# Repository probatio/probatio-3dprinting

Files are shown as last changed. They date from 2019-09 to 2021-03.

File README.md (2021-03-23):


# probatio-3dprinting
Probatio's models for 3D printing

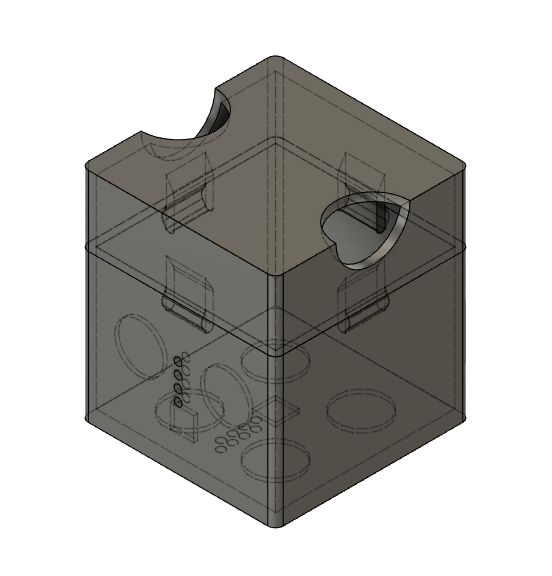
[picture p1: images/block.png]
probatio-block-3dp


[Model in Fusion 360](https://a360.co/2OMQyPX)

## Lateral support (2 parts)

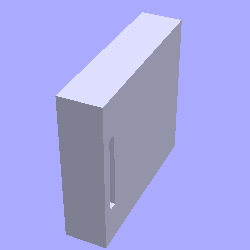
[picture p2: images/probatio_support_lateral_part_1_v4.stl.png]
probatio_support_lateral_part_1_v4


[probatio_support_lateral_part_1_v4](https://github.com/probatio/probatio-3dprinting/blob/master/stls/probatio_support_lateral_part_1_v4.stl)

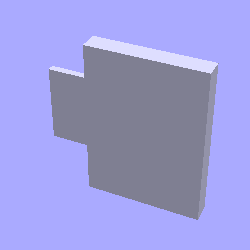
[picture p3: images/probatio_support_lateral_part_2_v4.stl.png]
probatio_support_lateral_part_2_v4


[probatio_support_lateral_part_2_v4](https://github.com/probatio/probatio-3dprinting/blob/master/stls/probatio_support_lateral_part_2_v4.stl)

## Lateral support (single part)

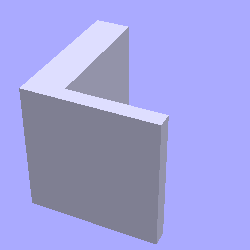
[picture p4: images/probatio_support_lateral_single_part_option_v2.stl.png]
probatio_support_lateral_single_part_option_v2


[probatio_support_lateral_single_part_option_v2](https://github.com/probatio/probatio-3dprinting/blob/master/stls/probatio_support_lateral_single_part_option_v2.stl)

## Neck support for Base 1x3

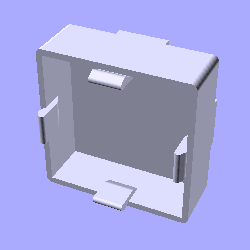
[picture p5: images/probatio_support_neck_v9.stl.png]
probatio_support_neck_v9


[probatio_support_neck_v9](https://github.com/probatio/probatio-3dprinting/blob/master/stls/probatio_support_neck_v9.stl)

## Hub Case (for M5StickC)

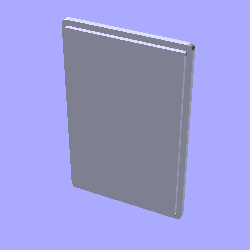
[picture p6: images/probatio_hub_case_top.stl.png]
probatio_hub_case_top


[probatio_hub_case_top](https://github.com/probatio/probatio-3dprinting/blob/master/stls/probatio_hub_case_top.stl)

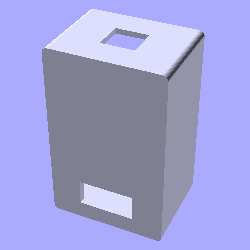
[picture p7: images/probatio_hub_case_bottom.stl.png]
probatio_hub_case_bottom


[probatio_hub_case_bottom](https://github.com/probatio/probatio-3dprinting/blob/master/stls/probatio_hub_case_bottom.stl)

## Block Tops

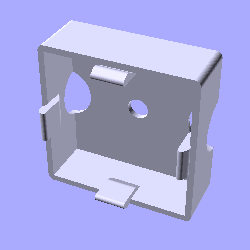
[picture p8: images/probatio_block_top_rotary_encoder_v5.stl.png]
probatio_block_top_rotary_encoder_v5


[probatio_block_top_rotary_encoder_v5](https://github.com/probatio/probatio-3dprinting/blob/master/stls/probatio_block_top_rotary_encoder_v5.stl)

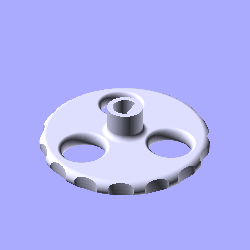
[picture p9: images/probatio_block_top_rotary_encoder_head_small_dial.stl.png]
probatio_block_top_rotary_encoder_head_small_dial


[probatio_block_top_rotary_encoder_head_small_dial](https://github.com/probatio/probatio-3dprinting/blob/master/stls/probatio_block_top_rotary_encoder_head_small_dial.stl)

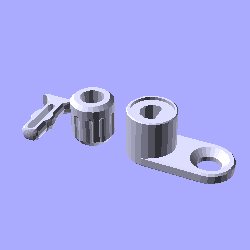
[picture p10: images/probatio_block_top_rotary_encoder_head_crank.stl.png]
probatio_block_top_rotary_encoder_head_crank


[probatio_block_top_rotary_encoder_head_crank](https://github.com/probatio/probatio-3dprinting/blob/master/stls/probatio_block_top_rotary_encoder_head_crank.stl)

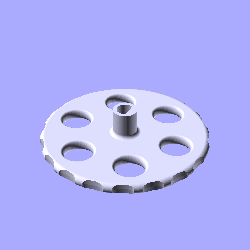
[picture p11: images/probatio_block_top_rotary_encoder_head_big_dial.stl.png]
probatio_block_top_rotary_encoder_head_big_dial


[probatio_block_top_rotary_encoder_head_big_dial](https://github.com/probatio/probatio-3dprinting/blob/master/stls/probatio_block_top_rotary_encoder_head_big_dial.stl)

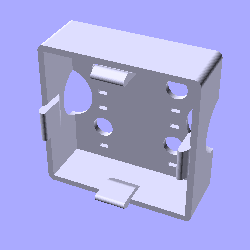
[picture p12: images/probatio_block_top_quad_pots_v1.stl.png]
probatio_block_top_quad_pots_v1


[probatio_block_top_quad_pots_v1](https://github.com/probatio/probatio-3dprinting/blob/master/stls/probatio_block_top_quad_pots_v1.stl)

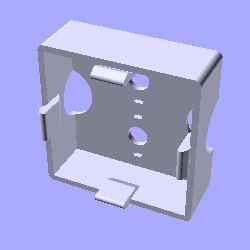
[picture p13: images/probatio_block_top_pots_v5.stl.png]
probatio_block_top_pots_v5


[probatio_block_top_pots_v5](https://github.com/probatio/probatio-3dprinting/blob/master/stls/probatio_block_top_pots_v5.stl)

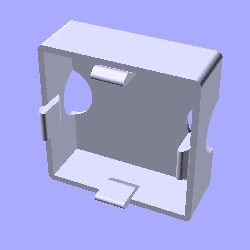
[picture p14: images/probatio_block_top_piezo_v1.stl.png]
probatio_block_top_piezo_v1


[probatio_block_top_piezo_v1](https://github.com/probatio/probatio-3dprinting/blob/master/stls/probatio_block_top_piezo_v1.stl)

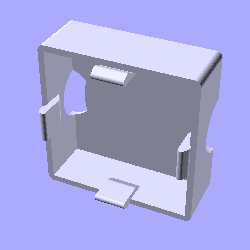
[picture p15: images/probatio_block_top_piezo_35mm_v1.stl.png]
probatio_block_top_piezo_35mm_v1


[probatio_block_top_piezo_35mm_v1](https://github.com/probatio/probatio-3dprinting/blob/master/stls/probatio_block_top_piezo_35mm_v1.stl)

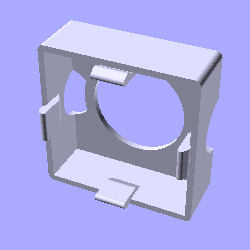
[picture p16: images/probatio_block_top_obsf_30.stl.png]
probatio_block_top_obsf_30


[probatio_block_top_obsf_30](https://github.com/probatio/probatio-3dprinting/blob/master/stls/probatio_block_top_obsf_30.stl)

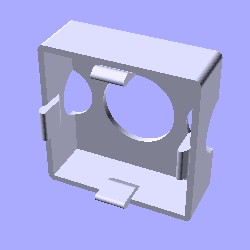
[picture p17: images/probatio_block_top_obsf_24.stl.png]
probatio_block_top_obsf_24


[probatio_block_top_obsf_24](https://github.com/probatio/probatio-3dprinting/blob/master/stls/probatio_block_top_obsf_24.stl)

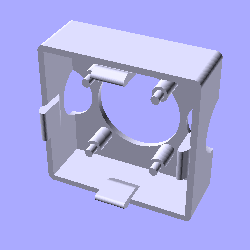
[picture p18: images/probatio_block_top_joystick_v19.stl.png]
probatio_block_top_joystick_v19


[probatio_block_top_joystick_v19](https://github.com/probatio/probatio-3dprinting/blob/master/stls/probatio_block_top_joystick_v19.stl)

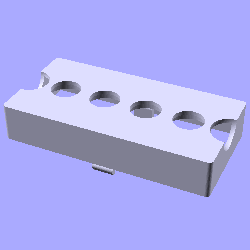
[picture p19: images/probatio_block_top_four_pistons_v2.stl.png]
probatio_block_top_four_pistons_v2


[probatio_block_top_four_pistons_v2](https://github.com/probatio/probatio-3dprinting/blob/master/stls/probatio_block_top_four_pistons_v2.stl)

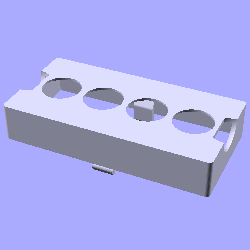
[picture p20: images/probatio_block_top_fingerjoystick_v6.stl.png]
probatio_block_top_fingerjoystick_v6


[probatio_block_top_fingerjoystick_v6](https://github.com/probatio/probatio-3dprinting/blob/master/stls/probatio_block_top_fingerjoystick_v6.stl)

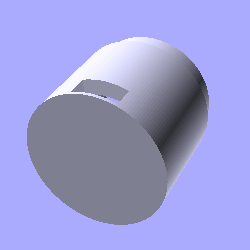
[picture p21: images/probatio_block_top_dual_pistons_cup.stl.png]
probatio_block_top_dual_pistons_cup


[probatio_block_top_dual_pistons_cup](https://github.com/probatio/probatio-3dprinting/blob/master/stls/probatio_block_top_dual_pistons_cup.stl)

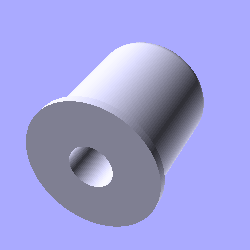
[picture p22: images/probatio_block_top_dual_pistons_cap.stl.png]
probatio_block_top_dual_pistons_cap


[probatio_block_top_dual_pistons_cap](https://github.com/probatio/probatio-3dprinting/blob/master/stls/probatio_block_top_dual_pistons_cap.stl)

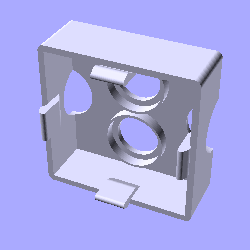
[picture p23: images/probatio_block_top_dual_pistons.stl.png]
probatio_block_top_dual_pistons


[probatio_block_top_dual_pistons](https://github.com/probatio/probatio-3dprinting/blob/master/stls/probatio_block_top_dual_pistons.stl)

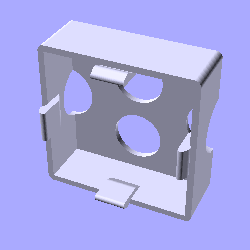
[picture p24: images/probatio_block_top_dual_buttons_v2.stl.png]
probatio_block_top_dual_buttons_v2


[probatio_block_top_dual_buttons_v2](https://github.com/probatio/probatio-3dprinting/blob/master/stls/probatio_block_top_dual_buttons_v2.stl)

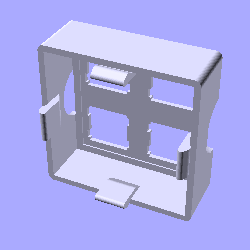
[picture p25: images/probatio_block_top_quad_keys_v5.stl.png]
probatio_block_top_quad_keys_v5


[probatio_block_top_quad_keys_v5](https://github.com/probatio/probatio-3dprinting/blob/master/stls/probatio_block_top_quad_keys_v5.stl)

probatio_block_top_breath_v1

[probatio_block_top_breath_v1](https://github.com/probatio/probatio-3dprinting/blob/master/stls/probatio_block_top_breath_v1.stl)

## Block Bottom 1x1

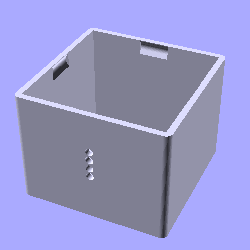
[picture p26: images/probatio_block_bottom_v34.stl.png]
probatio_block_bottom_v34


[probatio_block_bottom_v34](https://github.com/probatio/probatio-3dprinting/blob/master/stls/probatio_block_bottom_v34.stl)

## Block Joystick 4-DOFs 3x3

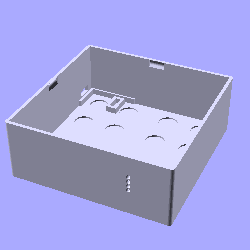
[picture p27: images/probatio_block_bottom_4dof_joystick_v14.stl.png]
probatio_block_bottom_4dof_joystick_v14


[probatio_block_bottom_4dof_joystick_v14](https://github.com/probatio/probatio-3dprinting/blob/master/stls/probatio_block_bottom_4dof_joystick_v14.stl)

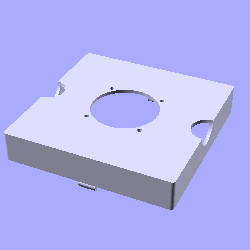
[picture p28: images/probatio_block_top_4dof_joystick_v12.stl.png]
probatio_block_top_4dof_joystick_v12


[probatio_block_top_4dof_joystick_v12](https://github.com/probatio/probatio-3dprinting/blob/master/stls/probatio_block_top_4dof_joystick_v12.stl)

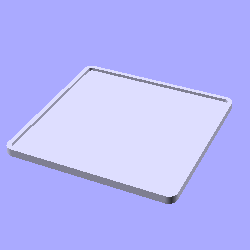
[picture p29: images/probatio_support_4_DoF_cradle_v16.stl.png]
probatio_support_4_DoF_cradle_v16


[probatio_support_4_DoF_cradle_v16](https://github.com/probatio/probatio-3dprinting/blob/master/stls/probatio_support_4_DoF_cradle_v16.stl)

## Bases

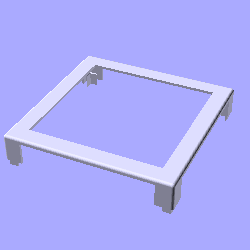
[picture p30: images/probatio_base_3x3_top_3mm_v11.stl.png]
probatio_base_3x3_top_3mm_v11


[probatio_base_3x3_top_3mm_v11](https://github.com/probatio/probatio-3dprinting/blob/master/stls/probatio_base_3x3_top_3mm_v11.stl)

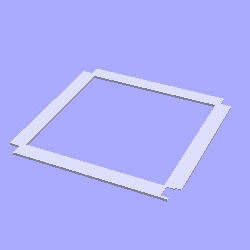
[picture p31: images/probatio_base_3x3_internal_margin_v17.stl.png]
probatio_base_3x3_internal_margin_v17


[probatio_base_3x3_internal_margin_v17](https://github.com/probatio/probatio-3dprinting/blob/master/stls/probatio_base_3x3_internal_margin_v17.stl)

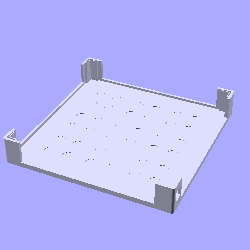
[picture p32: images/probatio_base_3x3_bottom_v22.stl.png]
probatio_base_3x3_bottom_v22


[probatio_base_3x3_bottom_v22](https://github.com/probatio/probatio-3dprinting/blob/master/stls/probatio_base_3x3_bottom_v22.stl)

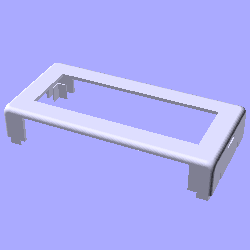
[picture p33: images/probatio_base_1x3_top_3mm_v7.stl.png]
probatio_base_1x3_top_3mm_v7


[probatio_base_1x3_top_3mm_v7](https://github.com/probatio/probatio-3dprinting/blob/master/stls/probatio_base_1x3_top_3mm_v7.stl)

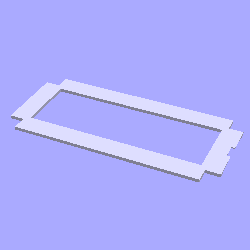
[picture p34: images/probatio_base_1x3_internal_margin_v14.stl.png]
probatio_base_1x3_internal_margin_v14


[probatio_base_1x3_internal_margin_v14](https://github.com/probatio/probatio-3dprinting/blob/master/stls/probatio_base_1x3_internal_margin_v14.stl)

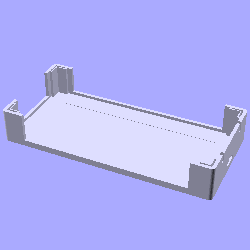
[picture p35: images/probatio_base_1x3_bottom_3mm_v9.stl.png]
probatio_base_1x3_bottom_3mm_v9


[probatio_base_1x3_bottom_3mm_v9](https://github.com/probatio/probatio-3dprinting/blob/master/stls/probatio_base_1x3_bottom_3mm_v9.stl)

## Dummy Blocks (for support)

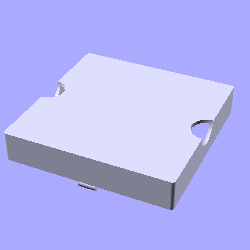
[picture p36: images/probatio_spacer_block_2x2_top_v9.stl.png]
probatio_spacer_block_2x2_top_v9


[probatio_spacer_block_2x2_top_v9](https://github.com/probatio/probatio-3dprinting/blob/master/stls/probatio_spacer_block_2x2_top_v9.stl)

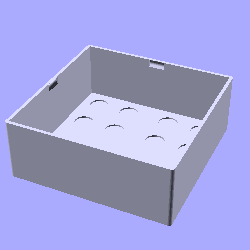
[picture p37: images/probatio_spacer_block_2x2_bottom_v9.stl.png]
probatio_spacer_block_2x2_bottom_v9


[probatio_spacer_block_2x2_bottom_v9](https://github.com/probatio/probatio-3dprinting/blob/master/stls/probatio_spacer_block_2x2_bottom_v9.stl)

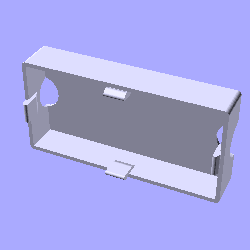
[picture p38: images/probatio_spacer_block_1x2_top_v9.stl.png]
probatio_spacer_block_1x2_top_v9


[probatio_spacer_block_1x2_top_v9](https://github.com/probatio/probatio-3dprinting/blob/master/stls/probatio_spacer_block_1x2_top_v9.stl)

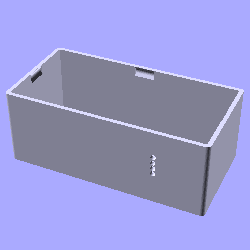
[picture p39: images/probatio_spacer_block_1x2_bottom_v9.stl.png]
probatio_spacer_block_1x2_bottom_v9


[probatio_spacer_block_1x2_bottom_v9](https://github.com/probatio/probatio-3dprinting/blob/master/stls/probatio_spacer_block_1x2_bottom_v9.stl)

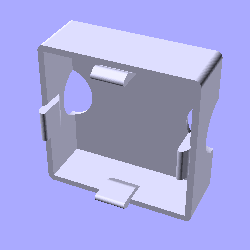
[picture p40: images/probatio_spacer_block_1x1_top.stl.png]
probatio_spacer_block_1x1_top


[probatio_spacer_block_1x1_top](https://github.com/probatio/probatio-3dprinting/blob/master/stls/probatio_spacer_block_1x1_top.stl)

probatio_spacer_block_1x1_bottom

[probatio_spacer_block_1x1_bottom](https://github.com/probatio/probatio-3dprinting/blob/master/stls/probatio_spacer_block_1x1_bottom.stl)

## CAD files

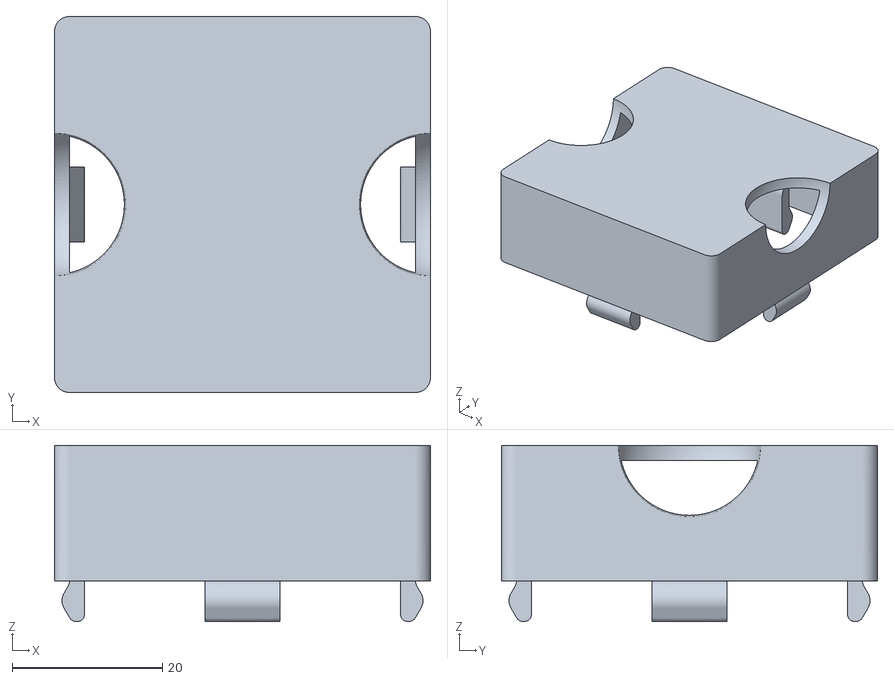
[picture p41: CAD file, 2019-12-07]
probatio-block-3dp-top-side-holes.stl
50.0 x 50.0 x 23.4

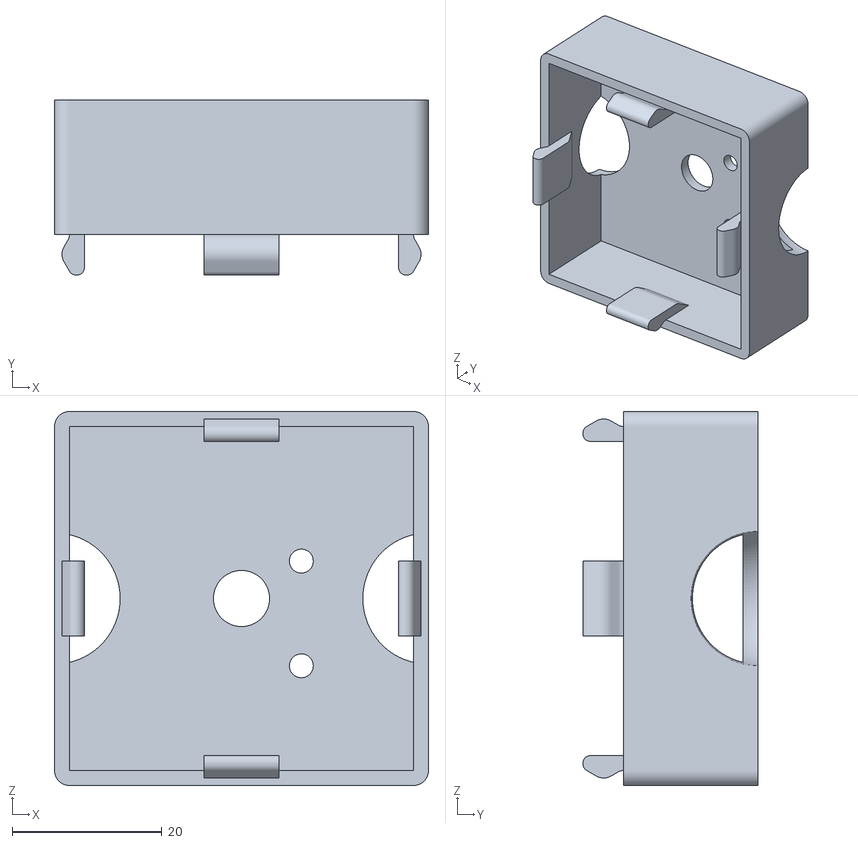
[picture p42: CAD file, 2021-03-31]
stls/probatio_block_top_rotary_encoder_unthreaded_with_breakout_board_v2.stl
50.0 x 23.4 x 50.0

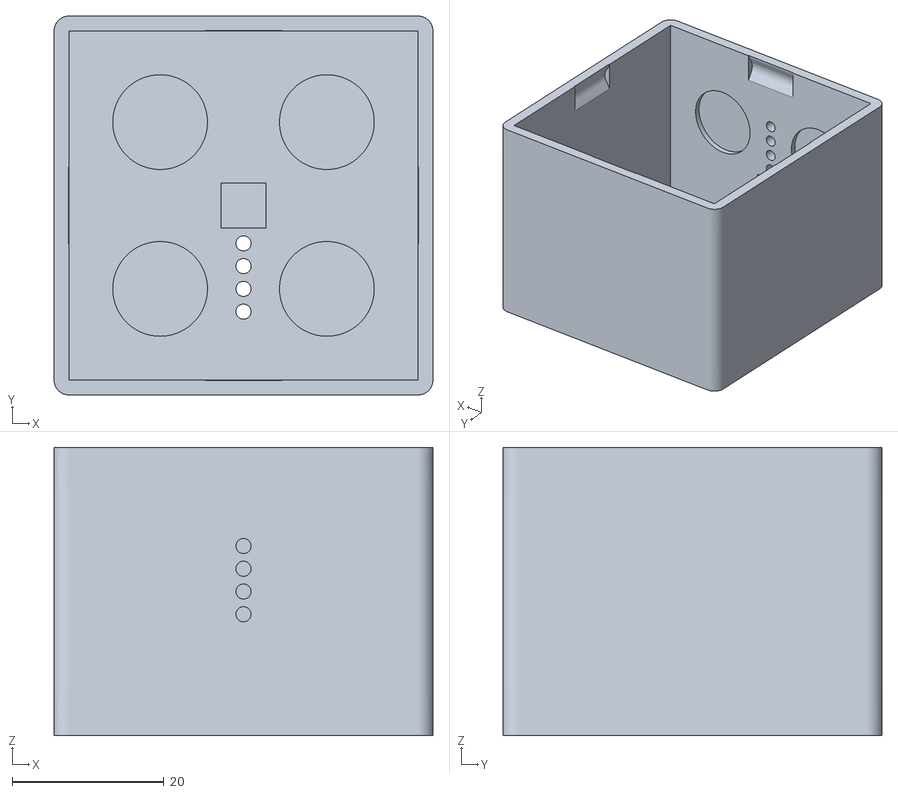
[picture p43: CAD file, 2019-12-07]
probatio-block-3dp-bottom-side-holes.stl
50.0 x 50.0 x 38.0

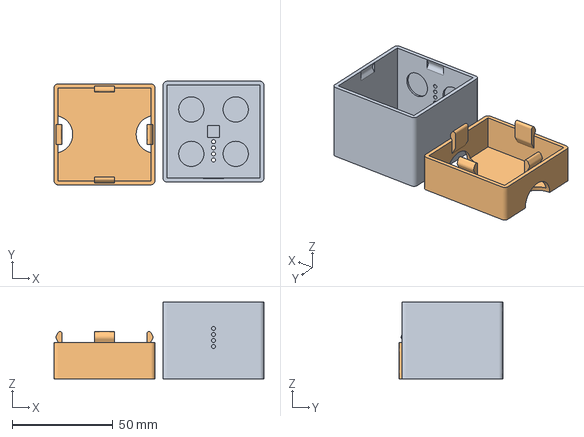
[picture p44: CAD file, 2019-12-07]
CE3_topbottom_probatio-block-3dp-.3mf
104.0 x 51.3 x 38.0 mm

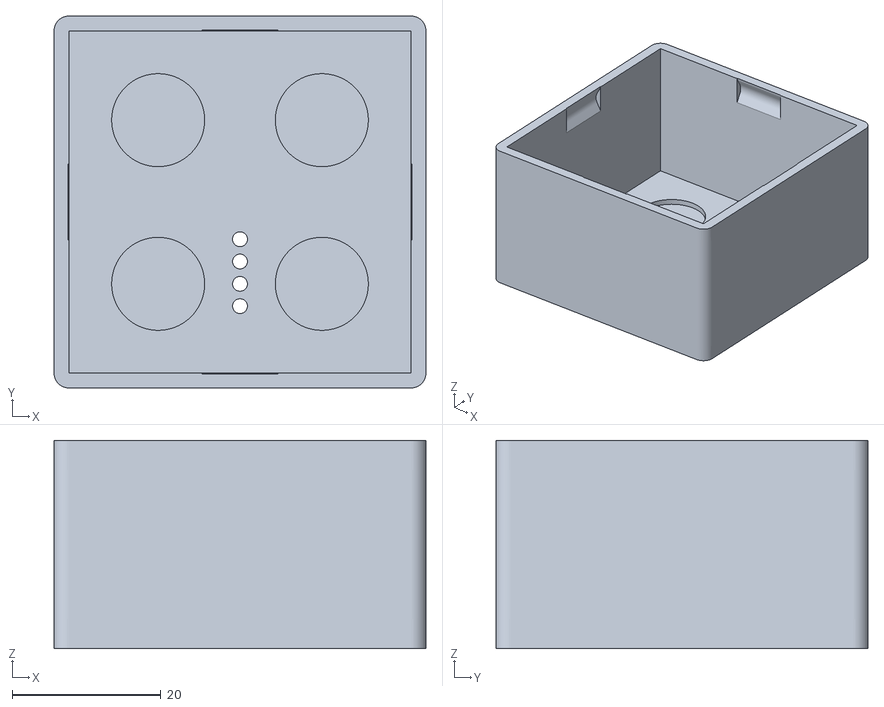
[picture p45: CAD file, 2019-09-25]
probatio-block-3dp-bottom.stl
50.0 x 50.0 x 28.0

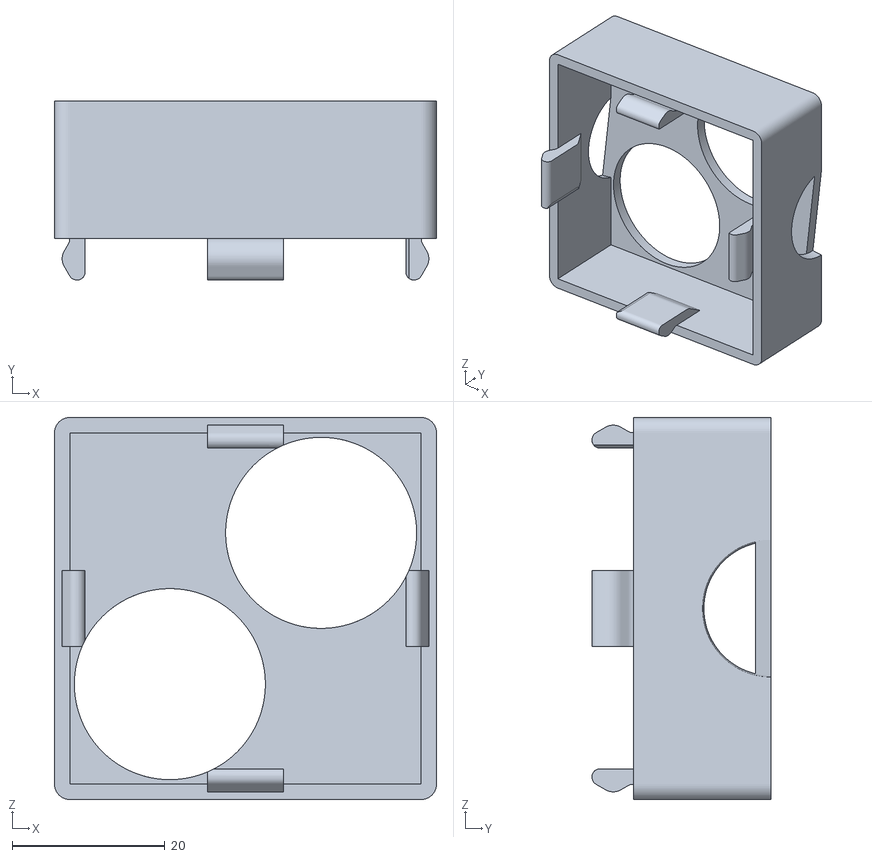
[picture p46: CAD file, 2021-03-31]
stls/probatio_block_top_dual_obsf_v1.stl
50.0 x 23.4 x 50.0

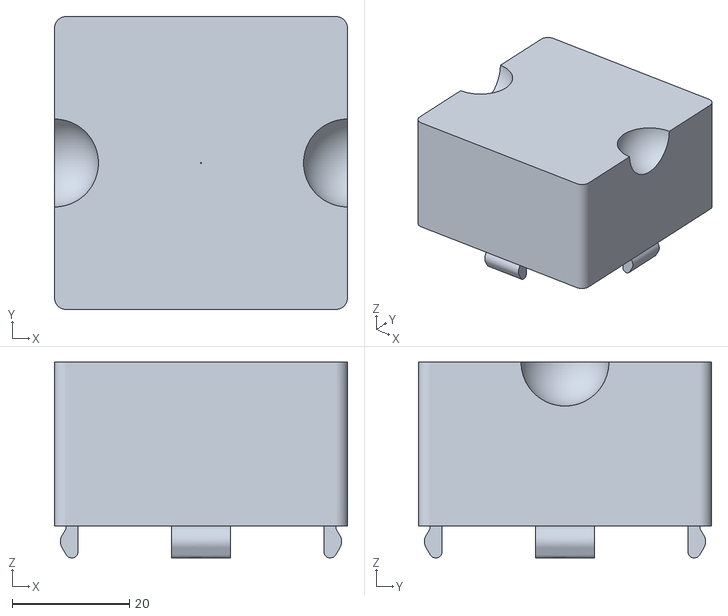
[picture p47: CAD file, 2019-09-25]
probatio-block-3dp-top.stl
50.0 x 50.0 x 33.4

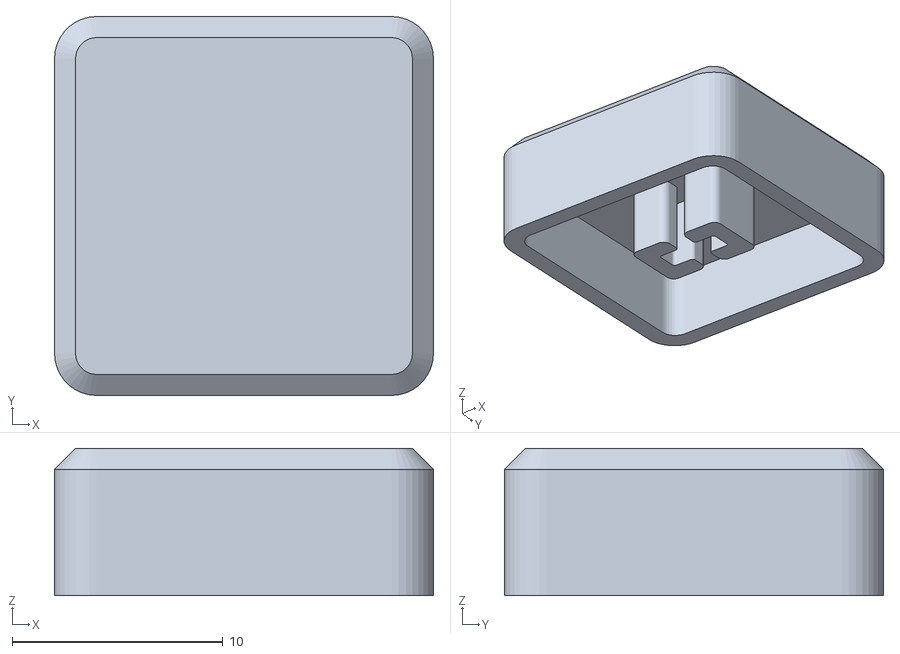
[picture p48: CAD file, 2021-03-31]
stls/probatio_block_top_quad_keys_keycap_v1.stl
18.0 x 18.0 x 7.00

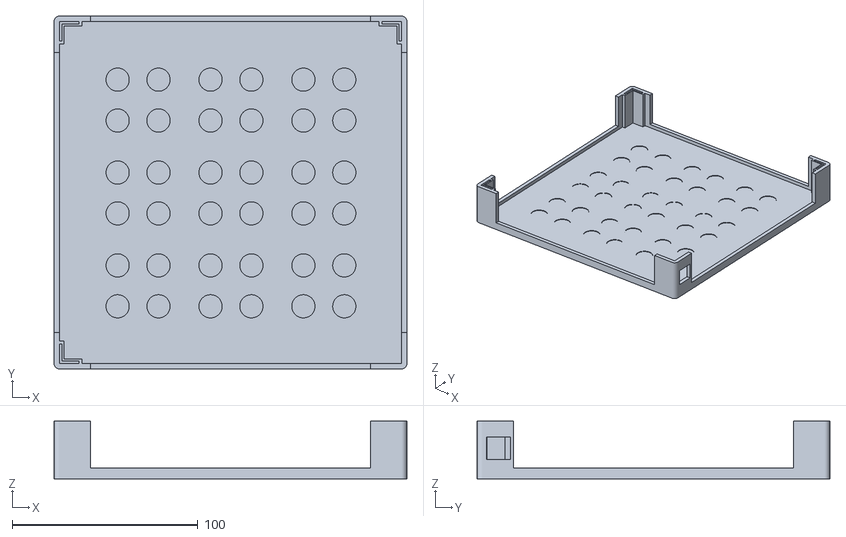
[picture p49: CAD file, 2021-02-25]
stls/probatio_base_3x3_bottom_v22.stl
190.0 x 190.0 x 31.0

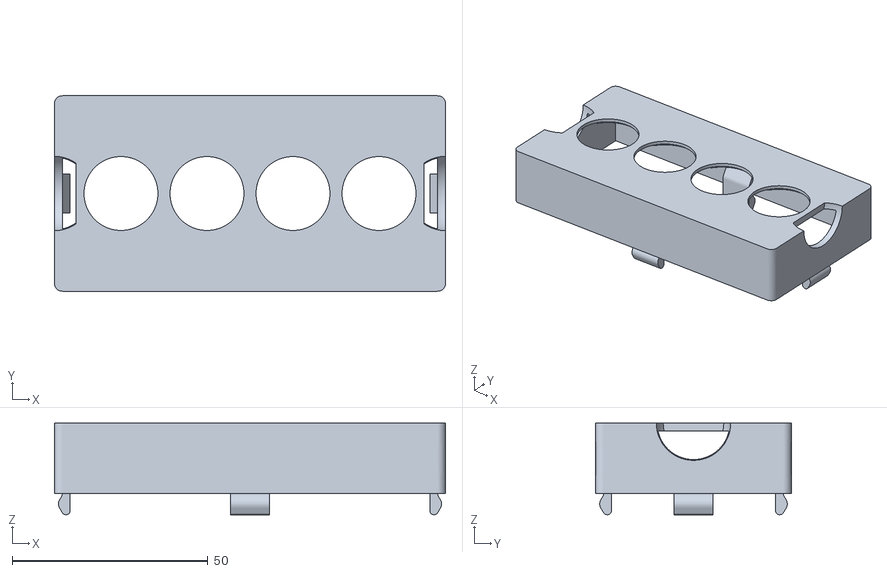
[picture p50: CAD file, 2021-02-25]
stls/probatio_block_top_fingerjoystick_v6.stl
100.0 x 50.0 x 23.4

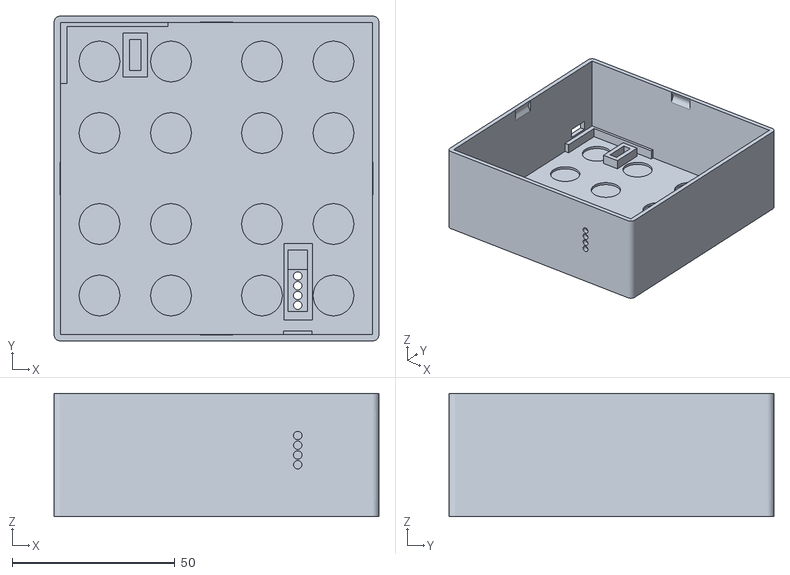
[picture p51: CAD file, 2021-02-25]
stls/probatio_block_bottom_4dof_joystick_v14.stl
100.0 x 100.0 x 38.0

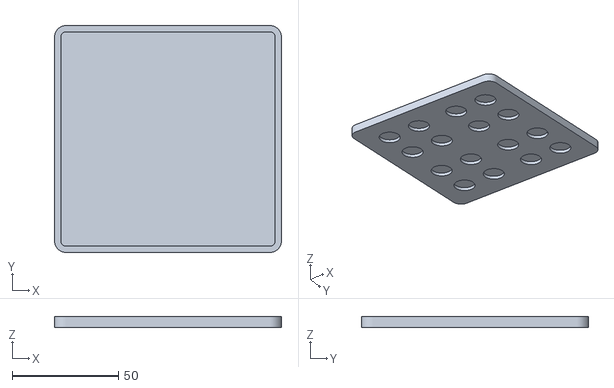
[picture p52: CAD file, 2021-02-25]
stls/probatio_support_4_DoF_cradle_v16.stl
107.0 x 107.0 x 5.00

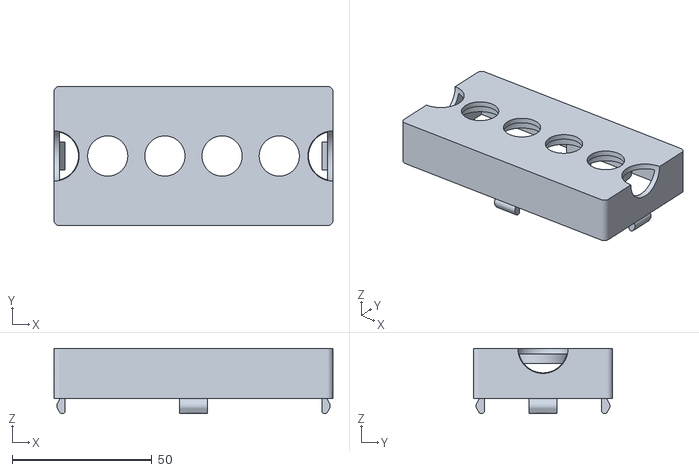
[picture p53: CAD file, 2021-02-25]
stls/probatio_block_top_four_pistons_v2.stl
100.0 x 50.0 x 23.4

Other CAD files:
stls/probatio_block_top_midi_usb_din_v1.stl
stls/probatio_block_top_midi_usb_din_rj12_v1.stl
stls/probatio_block_top_quad_buttons_v1.stl
stls/probatio_block_top_quad_pots_v3.stl
stls/probatio_block_top_obsf_30.stl
fusion360/Class_ Block (parametric generator) v9.f3d
fusion360/Class_ Block Top (generator) v4.f3z
fusion360/Probatio Assembly 1.0 v9.f3z
fusion360/Probatio_Pogo v2.f3z
fusion360/block-four-fingerjoysticks v8.f3d
fusion360/probatio_block_top_dual_pistons v16.f3z
fusion360/probatio_block_top_rotary_encoder_unthreaded_with_breakout_board_v2.f3d
old versions/probatio_block_3dp_v0.2 v10.f3d
old versions/probatio_v0.3_SIDE_HOLES v23.f3d
probatio_block_3dp_v0.2 v10.f3d
probatio_v0.3_SIDE_HOLES v23.f3d
stls/probatio_base_1x3_bottom_3mm_v9.stl
stls/probatio_base_1x3_internal_margin_v14.stl
stls/probatio_base_1x3_top_3mm_v7.stl
stls/probatio_base_3x3_internal_margin_v17.stl
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

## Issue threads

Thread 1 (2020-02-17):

improvements in probatio_base_1x3_top_3mm_v7

jtragtenberg, 2020-02-17:
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
When I printed the 1x3 base's top part, there were two problems.
1) the filleted edges were deformed because the top of the model was facing down, on the 3d printer's base, it would be best to remove the fillets, make it a sharp edge like the bottom's or I should try to print with the top part facing up in the printer, with supports.
2) The corners the fit with the bottom part broke in half. It could be thicker or shorter... Or maybe could have a snap-fit solution like the blocks

jtragtenberg, 2020-02-18:
It could be also because I used Octalapse: . I will try without time lapsing the print.

jtragtenberg, 2020-02-20:
No need for an improvement, It was the Octalapse and a clogged nozzle that caused the issue

Closed 2020-02-20.

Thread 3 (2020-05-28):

Stl base_1x3 file naming

jtragtenberg, 2020-05-28:
I see an inconsistency in the base files and the "neck" label. It took me a while to realize that for the 1x3 base to be made I needed this "support_neck" file. It would be better to understand if it was labeled "probatio_base_1x3_connection" and there could also be a file of the block base as a "base_1x3" name, like "probatio_base_1x3_connection_block". This way, to make just a 1x3 base I would know all the files I would need to print.

jtragtenberg, 2021-03-25:
Related to https://github.com/probatio/probatio/issues/10

DocSunset, 2021-03-25:
Also related to probatio/probatio#11

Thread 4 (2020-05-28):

form of the hole in the "probatio_base_1x3_bottom_3mm_v9" file could be the same as a connector to a hub

jtragtenberg, 2020-05-28:
I don't understand what is the purpose of the hole in the middle of the "probatio_base_1x3_bottom_3mm_v9" file. I suppose it is meant to pass the wires.
It took me a while to realize that at the side of the 1x3 base I should put a neck support and a block base... What if I want to just use a 1x3 base without the 3x3? souldn't there also be an option to put a connector to connect it directly to a hub? If there was a hole for this connector it could also serve to pass the wires to the block connector to another base.

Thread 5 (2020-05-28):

How well should I expect the snap-fit between the block bottom and block top?

jtragtenberg, 2020-05-28:
I got a loose fit, so I used some sticky tape to improve it, Is there a under-extrusion problem in my printer? Should the fit be perfect, without any play?

jtragtenberg, 2020-11-20:
It can't be loose, otherwise when taking the block out of the base it disconnects. We can use fita crepe to tighten the gap. This problem is due to the calibration of the 3D printer and we should do a parametric adjustment to this.

Closed 2020-11-20.

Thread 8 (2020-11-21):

Improve Bases printability/makeability

jtragtenberg, 2020-11-21:
They are hard to print/make because:
- They are too big (expensive, prone to errors, take too much time to make)
- The fittings need too much precision
- It takes too long to glue them together

jtragtenberg, 2020-11-21:
https://www.google.com.br/amp/s/www.instructables.com/Storage-Boxes-Made-Out-of-Cardboard-and-3D-Printed/%3famp_page=true

A mixed technique solution like this would me nice. 3D printed fitting edges with mdf, plexiglass... they would be a lot cheaper and sturdier

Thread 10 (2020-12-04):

Parametrize 3D model to adapt to differently calibrated 3D printers

jtragtenberg, 2020-12-04:

DocSunset, 2021-03-25:
This may remove the need for #12 for instance.

DocSunset, 2021-03-25:
Is the idea of "parametrize" that a given user making blocks will tweak parameters of the model to better work with their printer? Or is the goal that the model is flexible and redundant enough that tweaking isn't needed and the model works well across printers?

jtragtenberg, 2021-03-25:
The idea of this issue was to tweak parameters of the model to better work with their printer. But if we found a way to have a model that fits with any printer it would be better

DocSunset, 2021-03-25:
What sort of parameters would be tweaked?

jtragtenberg, 2021-03-25:
Block dimensions (to only change a few milimeters decimals), but this could be asily changed using the f3d file

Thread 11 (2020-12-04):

Improve Blocks 3D models for better adhesion

jtragtenberg, 2020-12-04:

DocSunset, 2021-03-25:
Any ideas how to make this improvement? Bigger magnets? Mating surface features? Snap fittings between blocks? What did you have in mind?

jtragtenberg, 2021-03-25:
I am testing now thicker magnets. I will see if it is still easy to remove a block with them. @filipecalegario has some cool ideas with mechanic supports.

DocSunset, 2021-03-25:
> I am testing now thicker magnets. I will see if it is still easy to remove a block with them.

An alternative to thicker magnets is to use multiple thin magnets.
- I think the change in attraction is very similar to using a single magnet as long as the thickness of the stack of magnets is similar
- you can glue just one magnet and later reclaim the rest stacked on top, easier for assembly and maintenance (probatio/probatio#8)
- You can adjust the strength by adding and removing magnets
- It may also be easier to source thinner magnets?

> @filipecalegario has some cool ideas with mechanic supports.

Interested to hear more about mechanic supports to improve adhesion. Are these separate from possible magnet supports for semi-permanent fixing? (#15)

jtragtenberg, 2021-03-25:
Yes, stacking thinner magnets would work. But buying a thicker one is cheaper than buying many thin ones. We can let the maker choose between this cost/flexibility tradeoff

DocSunset, 2021-03-25:
Good idea.

On Thu, Mar 25, 2021 at 11:04 AM João Tragtenberg ***@***.***>
wrote:

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

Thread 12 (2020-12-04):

Define a 3D printer calibration protocol to improve the Block snap-fittings

jtragtenberg, 2020-12-04:

DocSunset, 2021-03-25:
It may also be possible to design the snap fittings so they are less sensitive to poor print quality.

jtragtenberg, 2021-03-25:
My printer was systematically underextrusion and the layers were always systematically thinner. I tried everything to solve that and I could only fix this problem by buying a new extruder/hot end system now that I got money from the project.

I can’t think of a way for a model design that would work equally for a printer with such a problem without redesigning the model. Do you? That would be perfect.

DocSunset, 2021-03-25:
No, you’re absolutely right. We have to be able to assume that the printer is “working properly” at some baseline level. So is the idea of this issue to document a reasonable way of checking that your printer’s basic functionality is all working?

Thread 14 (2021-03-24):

Improve robustness of mechanical connection between main parts (blocks, bases, etc)

DocSunset, 2021-03-24:
This issue can serve as an index of specific issues related to mechanical connection between blocks and between blocks and bases.

Right now blocks are held together mainly by magnets and adjacent flat surfaces. This is adequate in many configurations, especially table- and lap-top, but not robust enough for vigorous gestures in some contexts.

Related issues:
#11

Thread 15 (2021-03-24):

Devise a means for strongly affixing blocks

DocSunset, 2021-03-24:
It would be useful if blocks could be strongly and semi-permanently affixed to bases and/or each other.

Possible implementations:

- screws (from base into the bottom or side of a block, integrated nut or threaded insert)
- tension rod
- tension rope/string/thread
- ???

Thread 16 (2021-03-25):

Design a version of probatio_block_top_dual_pistons_cap.stl with easy adaptation to other magnet sizes

jtragtenberg, 2021-03-25:
At the moment if could be a user variable in Fusion 360 f3d file, but in future it could be a openscad file

filipecalegario, 2021-03-26:
We could export some variant for possibly standard magnet sizes.

It's already possible to adjust a parameter in Fusion 360 file.

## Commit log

2019-09-25 Adding probatio-block-3dp
    [probatio-block-3dp-bottom.stl, probatio-block-3dp-top.stl, probatio_block_3dp_v0.2 v10.f3d]
2019-12-07 Adjusting block for holes and magnets on the side
    [CE3_topbottom_probatio-block-3dp-.3mf, probatio-block-3dp-bottom-side-holes.stl, probatio-block-3dp-top-side-holes.stl]
2019-12-07 Adding the Fusion 360 source code
    [probatio_v0.3_SIDE_HOLES v23.f3d]
2019-12-07 Organizing old files
    [probatio-block-3dp-bottom.stl, probatio-block-3dp-top.stl]
2019-12-07 Organizing more files
    [probatio_block_3dp_v0.2 v10.f3d]
2020-02-09 STL files after 2-week sprint in MTL
    [CE3_topbottom_probatio-block-3dp-.3mf, probatio-block-3dp-bottom-side-holes.stl, probatio-block-3dp-top-side-holes.stl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]
2020-11-27 Adding STLs of the probatio-hub
    [probatio-hub-case-bottom.stl, probatio-hub-case-top.stl]
2020-12-18 Adding Fusion 360 files
    [Class_ Block (parametric generator) v9.f3d, block-four-fingerjoysticks v8.f3d]
2020-12-18 Adding more Fusion 360 files
    [Class_ Block Top (generator) v4.f3z]
2020-12-18 Adding Fusion 360 archive
    [Probatio Assembly 1.0 v9.f3z]
2020-12-18 Adding Fusion 360 pcb-pogo
    [Probatio_Pogo v2.f3z]
2021-02-25 STLs folder
    [probatio-hub-case-bottom.stl, probatio-hub-case-top.stl, probatio_base_1x3_bottom_3mm_v9.stl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]
2021-02-25 Adding new blocks
    [probatio-base-3x3-bottom_v22.stl, probatio-block-bottom-4dof-joystick_v14.stl, probatio-block-top-4dof-joystick_v12.stl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]
2021-03-02 created quad_pot
    [probatio_block_top_quad_pots_v1.stl]
2021-03-15 Removing outdated STL of base3x3
    [probatio_base_3x3_bottom_3mm_v12.stl, probatio_base_3x3_bottom_v22.stl, probatio_block_bottom_4dof_joystick_v14.stl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]
2021-03-23 dummyu-blocks become spacer-blocks
    [probatio_spacer_block_1x1_bottom.stl, probatio_spacer_block_1x1_top.stl, probatio_spacer_block_1x2_bottom_v9.stl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]
2021-03-23 Replace dummy to spacer in README
2021-03-23 Updating block name: cherry_mx to quad_keys
    [probatio_block_top_quad_keys_v5.stl]
2021-03-23 Adding dual_pistons fusion360 files
    [probatio_block_top_dual_pistons v16.f3z]
2021-03-25 some new block tops I created
    [probatio_block_top_dual_obsf_v1.stl, probatio_block_top_midi_usb_din_rj12_v1.stl, probatio_block_top_midi_usb_din_v1.stl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]

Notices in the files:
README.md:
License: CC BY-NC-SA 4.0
